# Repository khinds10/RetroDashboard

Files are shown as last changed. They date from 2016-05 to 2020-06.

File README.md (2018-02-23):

# DashboardPI - Retro Display Dashboard
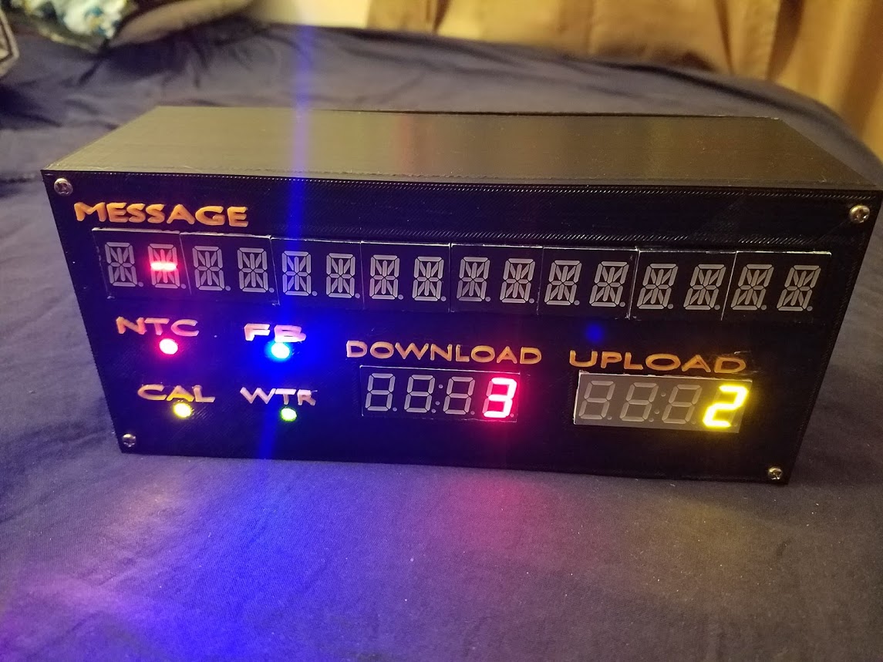
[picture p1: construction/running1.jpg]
Final Construction

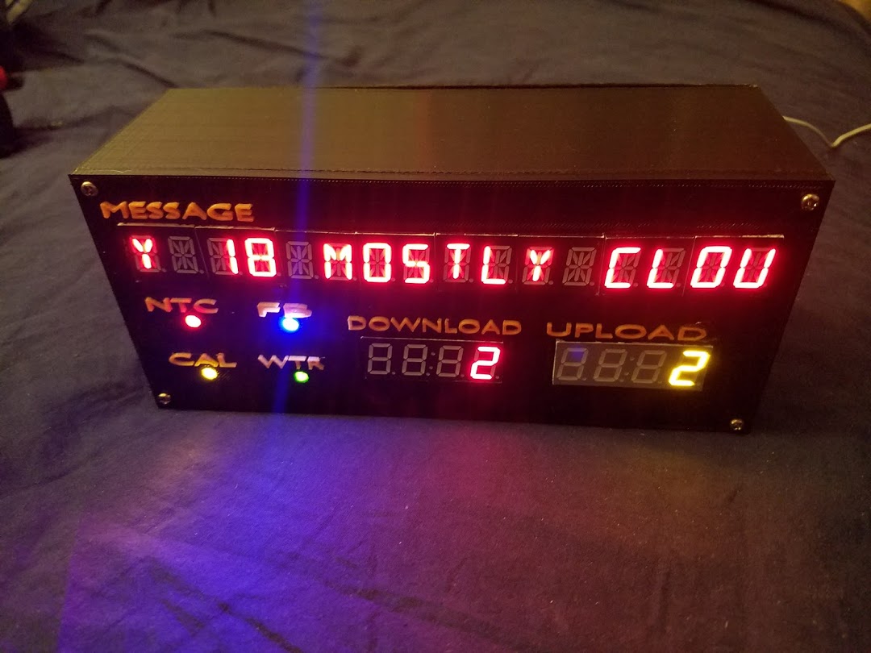
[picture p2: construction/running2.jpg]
Final Construction


#### Flashing RaspberriPi Hard Disk / Install Required Software (Using Ubuntu Linux)

Download "RASPBIAN JESSIE LITE"
https://www.raspberrypi.org/downloads/raspbian/

**Create your new hard disk for DashboardPI**
>Insert the microSD to your computer via USB adapter and create the disk image using the `dd` command
>
> Locate your inserted microSD card via the `df -h` command, unmount it and create the disk image with the disk copy `dd` command
> 
> $ `df -h`
> */dev/sdb1       7.4G   32K  7.4G   1% /media/XXX/1234-5678*
> 
> $ `umount /dev/sdb1`
> 
> **Caution: be sure the command is completely accurate, you can damage other disks with this command**
> 
> *if=location of RASPBIAN JESSIE LITE image file*
> *of=location of your microSD card*
> 
> $ `sudo dd bs=4M if=/path/to/raspbian-jessie-lite.img of=/dev/sdb`
> *(note: in this case, it's /dev/sdb, /dev/sdb1 was an existing factory partition on the microSD)*

**Setting up your RaspberriPi**

*Insert your new microSD card to the raspberrypi and power it on with a monitor connected to the HDMI port*

Login
> user: **pi**
> pass: **raspberry**

Change your account password for security
>`sudo passwd pi`

Enable RaspberriPi Advanced Options
>`sudo raspi-config`

Choose:
`1 Expand File System`

`9 Advanced Options`
>`A2 Hostname`
>*change it to "DashboardPI"*
>
>`A4 SSH`
>*Enable SSH Server*
>
>`A7 I2C`
>*Enable i2c interface*

**Enable the English/US Keyboard**

>`sudo nano /etc/default/keyboard`

> Change the following line:
>`XKBLAYOUT="us"`

**Reboot PI for Keyboard layout changes / file system resizing to take effect**
>$ `sudo shutdown -r now`

**Auto-Connect to your WiFi**

>`sudo nano /etc/wpa_supplicant/wpa_supplicant.conf`

Add the following lines to have your raspberrypi automatically connect to your home WiFi
*(if your wireless network is named "linksys" for example, in the following example)*

	network={
	   ssid="linksys"
	   psk="WIRELESS PASSWORD HERE"
	}

**Reboot PI to connect to WiFi network**

>$ `sudo shutdown -r now`
>
>Now that your PI is finally on the local network, you can login remotely to it via SSH.
>But first you need to get the IP address it currently has.
>
>$ `ifconfig`
>*Look for "inet addr: 192.168.XXX.XXX" in the following command's output for your PI's IP Address*

**Go to another machine and login to your raspberrypi via ssh**

> $ `ssh pi@192.168.XXX.XXX`

**Start Installing required packages**

>$ `sudo apt-get update`
>
>$ `sudo apt-get upgrade`
>
>$ `sudo apt-get install vim git python-smbus i2c-tools python-imaging python-smbus build-essential python-dev rpi.gpio python3 python3-pip`

**Update local timezone settings

>$ `sudo dpkg-reconfigure tzdata`

`select your timezone using the interface`

**Setup the simple directory `l` command [optional]**

>`vi ~/.bashrc`
>
>*add the following line:*
>
>`alias l='ls -lh'`
>
>`source ~/.bashrc`

**Fix VIM default syntax highlighting [optional]**

>`sudo vi  /etc/vim/vimrc`
>
>uncomment the following line:
>
>_syntax on_

**Install i2c Backpack Python Drivers**

>$ `git clone https://github.com/adafruit/Adafruit_Python_LED_Backpack`

>$ `cd Adafruit_Python_LED_Backpack/`

>$ `sudo python setup.py install`

# Supplies Needed

Raspberry PI or Pi Zero

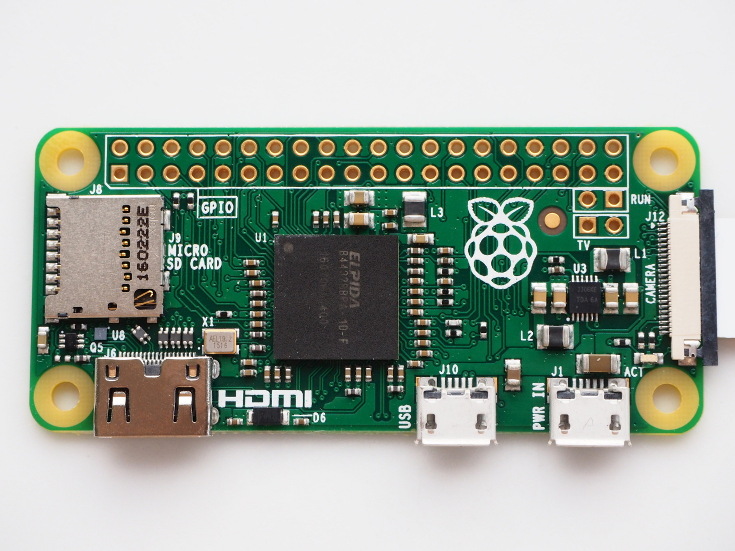
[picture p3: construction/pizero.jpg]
PiZero


0.56" 4-Digit 7-Segment Display w/I2C Backpack (x2)

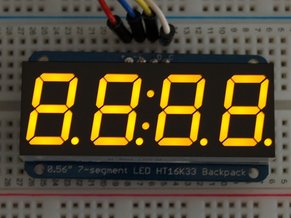
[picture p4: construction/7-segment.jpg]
7 Segment Display


Quad Alphanumeric Display - 0.54" Digits w/ I2C Backpack (x4)

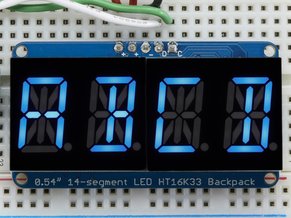
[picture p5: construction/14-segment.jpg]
14 Segment Display


LED Lights (x4)

LED Lights

# Building the Dashboard

## 1) Using a 3d printer, print the cover, box and back panels

Using the following 3 STL files in the `/construction/3D Print/` folder, print out the cover, box and back of the case to assemble.
>Dashboard-cover.stl
>Dashboard-box.stl
>Dashboard-back.stl

## 2) Solder Unique Display Jumpers
*NOTE: All the I2C backpacks must be soldered on the back of each of the displays, the backpacks come with the display and must all be soldered on first.*

For each of the I2C backpack displays you must solder the jumpers on the back in the **all the possible combinations** to have your RaspberriPI I2C interface to recognize each display with a **unique address**.  

Leave the first display with no jumper soldered, the 2nd with the farthest right soldered, the 3rd with only the middle soldered and so on...  Eventually you'll have to solder jumpers in all the combinations of 2 at a time connected and the final display with all 3 jumpers soldered to be connected.

*There's a total of 3 pins so you should have a total combination of 8 unique combinations.*

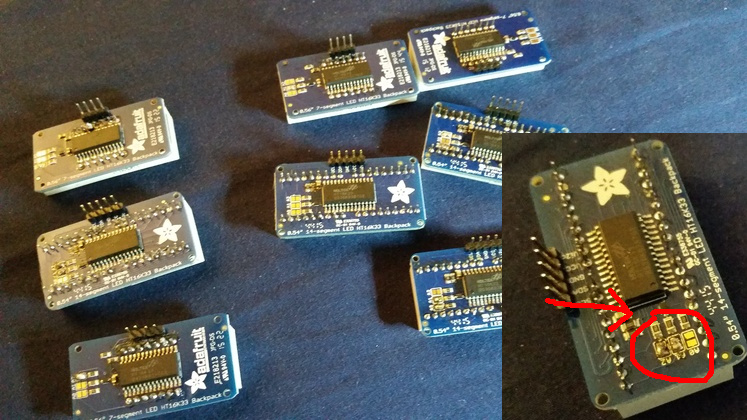
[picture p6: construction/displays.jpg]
Solder Unique Display Jumpers


## 3) Mount Displays in box
Using a hot glue gun, mount the displays in the holes and glue them in place.  The LED lights may hold by friction from the 3D printed design, else use hot glue to hold them in place as well.

**NOTE: I have written down on the back of the box cover the HEX addresses x70 - x77 that each display has based on the soldering jumpers (see section #2)**

## 4) Wiring all Displays

Each of the 14 segment alpha numeric displays needs to have a connection to the RaspberryPI GND, 5V and 3V pins.  The 7 segment display only needs connectivity to the GND and 5V pins.

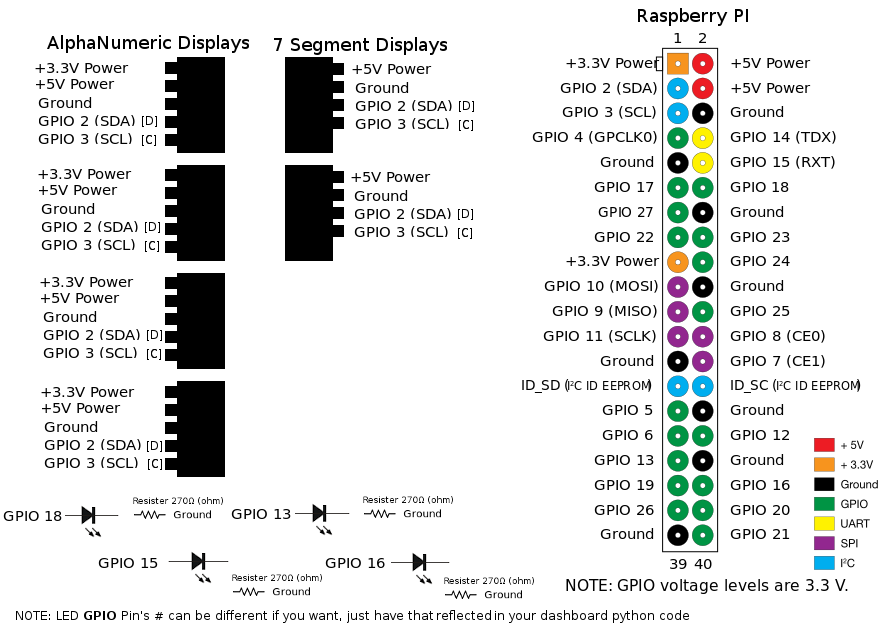
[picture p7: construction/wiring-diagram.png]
Wiring Diagram


I've used standard jumper wires to connect to all the pins on the display / RaspberryPI pins and grouped the common connections (all the GND wires, 5V wires) with a wirenut.

Each LED light needs to have a 270 ohm resister solder to the ground (short) pin and connect each positive LED pin to the corresponding GPIO pins on the PI, I've used GPIO pins 18, 13, 15 and 16.

For each display in the dashboard ALL of the D and C pins need to be connected to the SCL and SDA pins on the PI.

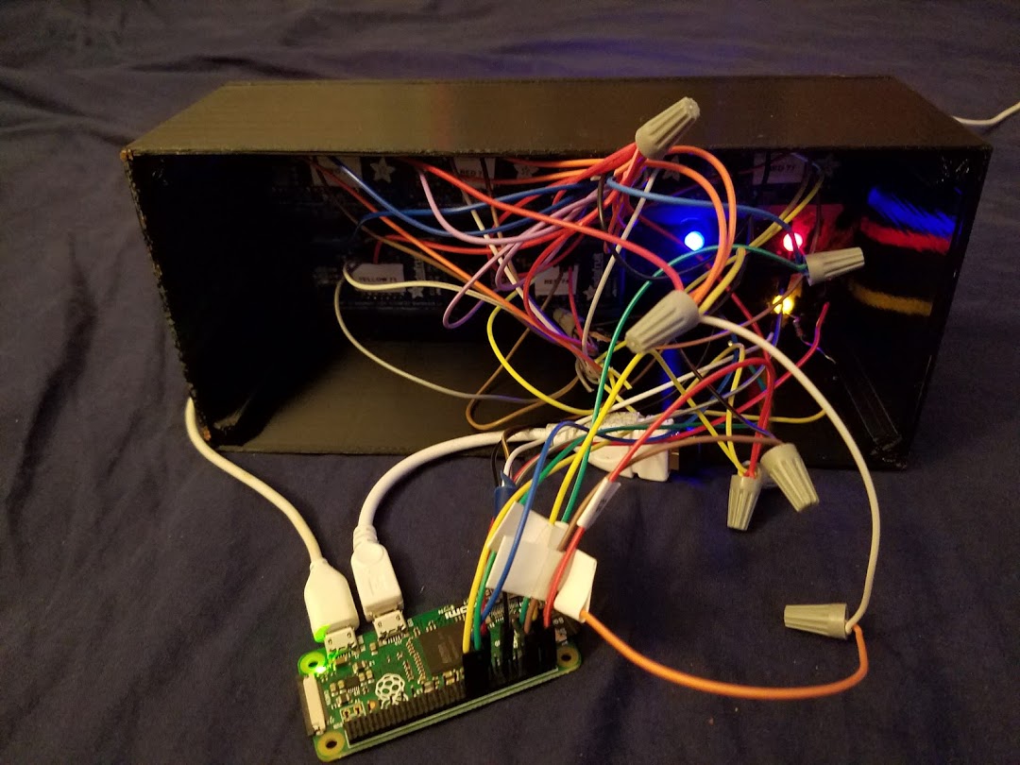
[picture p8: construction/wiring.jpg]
Mount Displays

## 5) Finished (Final Touches)

**Screw the front cover and back panel to the main box**

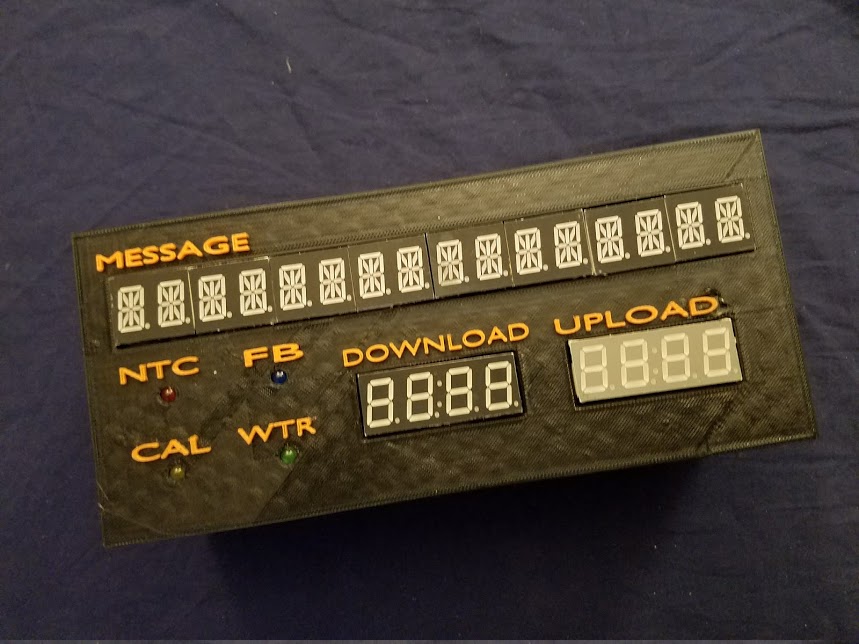
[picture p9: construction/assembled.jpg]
Front

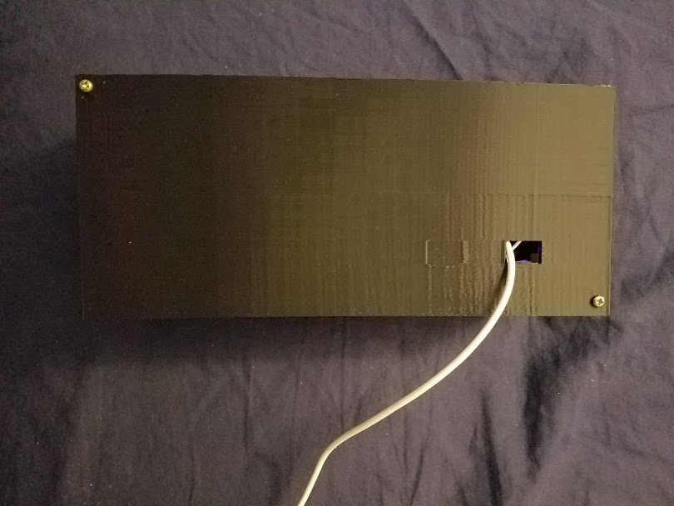
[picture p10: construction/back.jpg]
Back back


You're now ready to run the Dashboard!

## 7) Install Central Webhost 
This project includes a small PHP server that you can host on almost any low cost linux webhost.  From this project copy the files from the "server/" folder and place them on your PHP webhost and remember the domain name.  
> For our example it will be installed on a hypothetical host with the public domain name of: www.mydashboard.com

The **server/README.md** file contains all the details about how to get/set message values, measurement values and flag values to the PHP server.  These values will then be listened for on the Retrodashboard to display to you as output via the alphanumeric / numeric and led lights turning on and off.

## 8) Install & Run Dashboard Drivers

Start up your RaspberryPi and make sure the I2C bus recognizes all your connected 7/14 segment displays. 
*[each display is given a unique address described above by how you solder each display's jumpers in different combinations]*

If you have all 8 displays with jumpers soldered in all 8 combinations, you should have the following output for the `i2cdetect` command:

`sudo i2cdetect -y 1`
     
>    0  1  2  3  4  5  6  7  8  9  a  b  c  d  e  f
>
> 00:          -- -- -- -- -- -- -- -- -- -- -- -- -- 
> 
> 10: -- -- -- -- -- -- -- -- -- -- -- -- -- -- -- -- 
> 
> 20: -- -- -- -- -- -- -- -- -- -- -- -- -- -- -- -- 
> 
> 30: -- -- -- -- -- -- -- -- -- -- -- -- -- -- -- -- 
> 
> 40: -- -- -- -- -- -- -- -- -- -- -- -- -- -- -- -- 
> 
> 50: -- -- -- -- -- -- -- -- -- -- -- -- -- -- -- -- 
> 
> 60: -- -- -- -- -- -- -- -- -- -- -- -- -- -- -- -- 
> 
> 70: 70 71 72 73 74 75 76 77

*(in this case all the displays numbered 0 to 7 are being recognized on the PI as I2C available devices)*

**Install all 3 python driver scripts from this project (in the dashboard/ folder) to your home directory of the RaspberryPI. **
So your PI has the following home directory files:

`cd ~`
`ls -lh`

    -rwxrwxr-x 1 pi pi 2.8K May 21 01:56 alphanum.py
    -rwxrwxr-x 1 pi pi 2.2K May 21 01:54 dashboard.py
    -rwxrwxr-x 1 pi pi 1.4K May 21 02:36 indicators.py

Edit each python scripts variable to reference your running PHP data server (see Step 7)

	dashboardServer = 'CHANGE TO YOUR SERVER.com'

**alphanum.py**

*Change the python code to reflect the HEX addresses each display is assigned based on the solder jumpers (see section #2)*

	display1 = AlphaNum4.AlphaNum4(address=0x77, busnum=1)
	display2 = AlphaNum4.AlphaNum4(address=0x76, busnum=1)
	display3 = AlphaNum4.AlphaNum4(address=0x75, busnum=1)
	display4 = AlphaNum4.AlphaNum4(address=0x73, busnum=1)
	
**dashboard.py**

*Change the python code to reflect the HEX addresses each display is assigned based on the solder jumpers (see section #2)*

	blueDisplay = SevenSegment.SevenSegment(address=0x70, busnum=1) 
	yellowDisplay = SevenSegment.SevenSegment(address=0x71, busnum=1) 
	greenDisplay = SevenSegment.SevenSegment(address=0x72, busnum=1) 
	redDisplay = SevenSegment.SevenSegment(address=0x74, busnum=1)
	
**indicators.py**

*Change the python code to reflect the GPIO pin numbers each LED is assigned based on your exact wiring (I've used GPIO pins: 13,15,16,18)

	GPIO.setup(18, GPIO.OUT)
	GPIO.output(18,GPIO.LOW)
	GPIO.setup(13, GPIO.OUT)
	GPIO.output(13,GPIO.LOW)
	GPIO.setup(15, GPIO.OUT)
	GPIO.output(15,GPIO.LOW)
	GPIO.setup(16, GPIO.OUT)
	GPIO.output(16,GPIO.LOW)

Now that your 3 scripts are pointing to your own data server you're now ready to run the dashboard to display your output.

Run the following commands to start your Dashboard displays.

$  `nohup python indicators.py > indicators.out &`

$  `nohup python dashboard.py > dashboard.out &`

$  `nohup python alphanum.py > alphanum.out &`

This will allow you to logout of your PI and have the python drivers remain running as a background process, if they do fail for any reason, the error message will be found in the [.out] from the commands above.

**Run Displays at system startup**

Place the following entries in the Dashboard crontab to have it run the scripts on system start/reboot.  Note: logging to [.out] files has been supressed in this case to /dev/null if you have any errors occuring.

$ `crontab -e`

`@reboot nohup python /home/pi/indicators.py >/dev/null 2>&1`
`@reboot nohup python /home/pi/dashboard.py >/dev/null 2>&1`
`@reboot nohup python /home/pi/alphanum.py >/dev/null 2>&1`

## 9) Running Plugins for Populating Display Data

#### (These plugins run on different machines of your choosing for the dashboard to then monitor them)

The **'plugins/'** folder contains plugins to get started populating the central server with information that the dashboard will display as output.

**network-monitor.py**

*This plugin will persist to the central data hub local network information such as your current upload and download speed in KBPS.*

**Software Requirements:**

ifstat is required

	sudo apt-get install ifstat

Configure and run the script:

	dashboardServer = 'CHANGE TO YOUR SERVER.com'

$  `nohup python network-monitor.py > network-monitor.out &`

**server-monitor.py**

*This plugin will persist to the central data hub local CPU usage and temperature statistics.*

**Software Requirements:**

psensor-server is required

	sudo apt-get install psensor-server

Configure the script:

	dashboardServer = 'CHANGE TO YOUR SERVER.com'

Run pensor server on port 17510, then run the server monitor script:

$ `nohup psensor-server -p 17510 > /dev/null 2>&1`

$ `nohup python server-monitor.py > server-monitor.out &`

**DashboardPhone/**

*This is a fully functional Android App that runs on your phone as a service and will persist to the central data hub notifications and indicator flags (coming soon).*

**Configure the App**
You need to update the settings.java file with your local settings

		// host with the PHP server script installed for the RetroDashboard
		public static String remoteDashboardHost = "CHANGE TO YOUR SERVER.com";
	
		// create a list of notifications (by title) your phone always produces but don't need to broadcast
		public static String[] ignoredNotifications = new String[] { "Privacy Guard active", "Change keyboard" };

**Build the App**

Using an Android IDE, import the project locally and build it to an APK file.  Install the APK on your phone locally and it should start working for you.

**PushBullet/**

*Using the pushbullet app for your phone, signup to recieve an API key to have a simple python script be able to capture and push data hub notifications and indicator flags*

Install Python 3.5 for asyncio functionality

	sudo apt-get update
	sudo apt-get install build-essential tk-dev
	sudo apt-get install libncurses5-dev libncursesw5-dev libreadline6-dev
	sudo apt-get install libdb5.3-dev libgdbm-dev libsqlite3-dev libssl-dev
	sudo apt-get install libbz2-dev libexpat1-dev liblzma-dev zlib1g-dev

If one of the packages cannot be found, try a newer version number (e.g. libdb5.4-dev instead of libdb5.3-dev).

	wget https://www.python.org/ftp/python/3.5.2/Python-3.5.2.tgz
	tar zxvf Python-3.5.2.tgz
	cd Python-3.5.2
	./configure --prefix=/usr/local/opt/python-3.5.2
	make
	sudo make install
	sudo ln -s /usr/local/opt/python-3.5.2/bin/pydoc3.5 /usr/bin/pydoc3.5
	sudo ln -s /usr/local/opt/python-3.5.2/bin/python3.5 /usr/bin/python3.5
	sudo ln -s /usr/local/opt/python-3.5.2/bin/python3.5m /usr/bin/python3.5m
	sudo ln -s /usr/local/opt/python-3.5.2/bin/pyvenv-3.5 /usr/bin/pyvenv-3.5
	sudo ln -s /usr/local/opt/python-3.5.2/bin/pip3.5 /usr/bin/pip3.5
	cd ~
	echo 'alias python35="/usr/local/opt/python-3.5.2/bin/python3.5"' >> .bashrc
	echo 'alias idle35="/usr/local/opt/python-3.5.2/bin/python3.5"' >> .bashrc

Install the python3 dependancies

	sudo apt-get install python3-setuptools
	sudo apt-get install python3-pip
	pip3 install asyncpushbullet

*Optional way* Download the python repository directly to obtain the python dependancies without the use of pip installing it

    git clone https://github.com/rharder/asyncpushbullet
    cd asyncpushbullet && sudo /usr/local/opt/python-3.5.2/bin/python3.5 setup.py install

Copy the `PushBullet/` folder of the dashboard `plugins/` from this project to the dashboard pi.

Visit the pushbullet settings page in your account to generate an API key to use
https://www.pushbullet.com/#settings

Configure your `pushbullet-listener.py` script to have the correct API and dashboard central host

	# your API Key from PushBullet.com
	API_KEY = "o.XXXYYYZZZ111222333444555666"

	# dashboard central server host
	dashboardServer = 'MY-SERVER-HERE.com'

Add the script to start at dashboard boot and restart your dashboard pi

$ `crontab -e`

`@reboot nohup /usr/local/opt/python-3.5.2/bin/python3.5 /home/pi/PushBullet/pushbullet-listener.py >/dev/null 2>&1`

*Optional Date and Time Output* - instead of having internet upload/download speed use the following script to show the date and time instead

In the Crontab Change:

`@reboot nohup python /home/pi/dashboard.py >/dev/null 2>&1`

to: 

`@reboot nohup python /home/pi/date-time.py >/dev/null 2>&1`

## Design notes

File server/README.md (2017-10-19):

# RetroDashboard Central Data Hub

The following criteria will explain how to get information to output on your RetroDashboard as well as set it from various "plugins" you can write on your own.
*This is a small PHP script to place on a webhost of your choosing.  It has the following API to get and set information to it. Note: don't forget to include the .htaccess file for proper URL routing to take place.*

## API

	http://myhost/message
		(get the current message set)

	http://myhost/message/set
		(HTTP POST a raw string value to this URL to set a new message)
	
	http://myhost/flag/{id}
		(get the current boolean status of the flag by integer: {id})

	http://myhost/flag/all
		(get all the current boolean status of all the flags as an array)

	http://myhost/flag/{id}/set
		(set the current boolean status to 'true' for the flag by integer: {id})

	http://myhost/flag/{id}/unset
		(set the current boolean status to 'false' for the flag by integer: {id})
	
	http://myhost/reading/{id}
		(get the current averaged value for the reading by integer: {id})

	http://myhost/reading/all
		(get the current averaged value for all the readings as an array)

	http://myhost/reading/{id}/set
		(HTTP POST a raw numeric value to this URL to add a new value to the current calculated average)  
			-- see below for how many values in total are compiled to the average value

## Configuation

The 'readings' values are calculated as averages of a certain number of recent persisted reading numeric values. Set the following constant to how many of the most recent readings should be included to produce the average.

***$readingsAverageLimit = 5;***

## Datastore	
Server will persist values to simple files located by naming conventions below. Note: {id} will be replaced by the real integer presented by the incoming request's URL.

	$valueFileFolder = 'values' (name of the folder to contain the measurement files)
	$messageFileName = 'message.msg' (name of the message text file)
	$readingsFilesNames = 'reading{id}.avg' (name of the CSV averaged readings file)
	$flagFilesNames = 'flag{id}.flg' (name of the boolean flag value flag file)

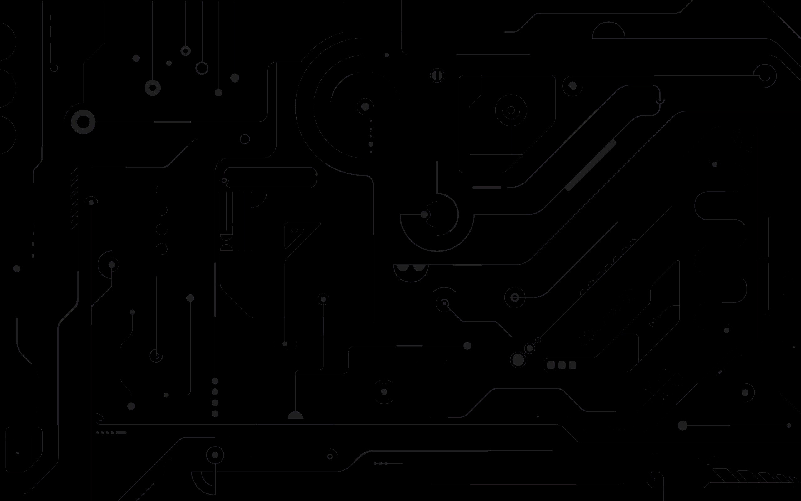
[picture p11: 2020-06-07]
server/img/background.jpg

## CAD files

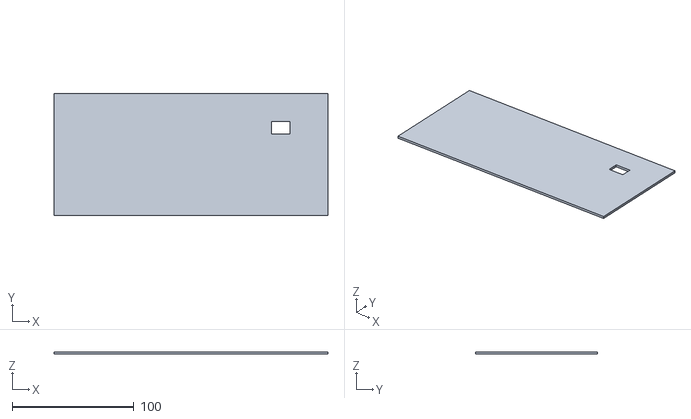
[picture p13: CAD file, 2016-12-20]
construction/3D Print/Dashboard-back.stl
225.0 x 100.0 x 2.00

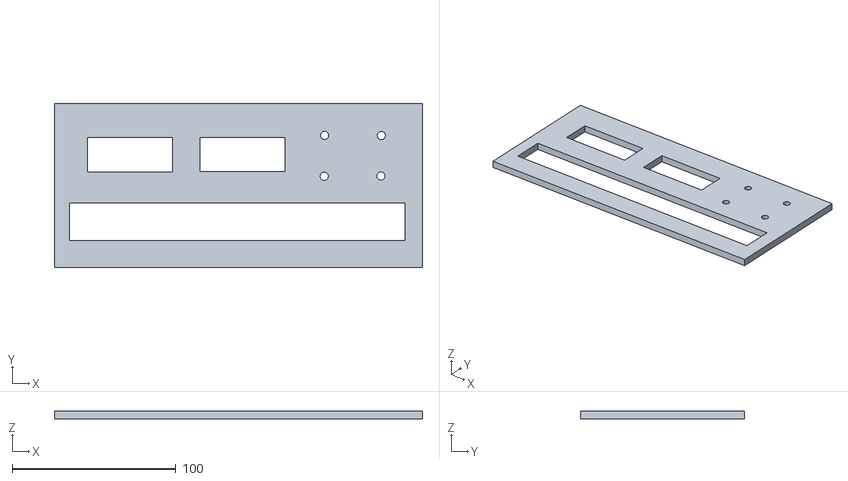
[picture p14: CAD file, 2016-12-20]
construction/3D Print/Dashboard-cover.stl
225.0 x 100.0 x 5.00

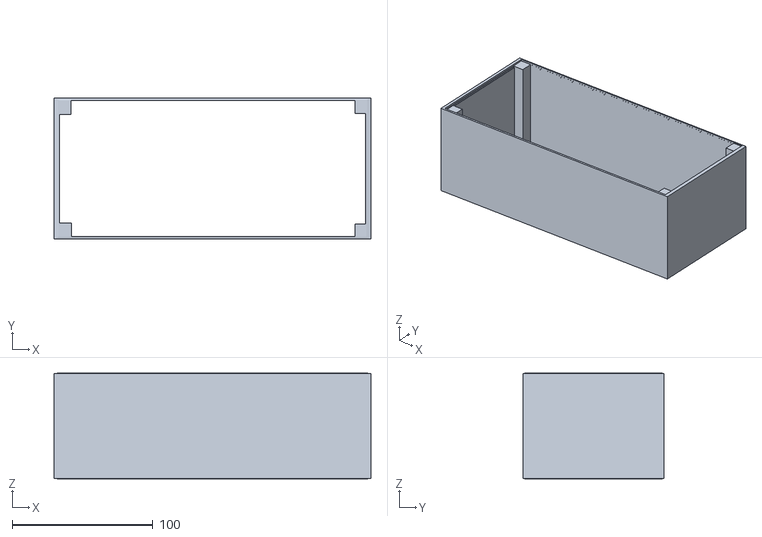
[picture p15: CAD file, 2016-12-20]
construction/3D Print/Dashboard-box.stl
225.0 x 100.0 x 75.0

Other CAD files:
construction/3D Print/Dashboard-back.blend
construction/3D Print/Dashboard-box.blend
construction/3D Print/Dashboard-cover.blend

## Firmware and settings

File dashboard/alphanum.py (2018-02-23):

#!/usr/bin/python
# RetroDashboard AlphaNumeric Messages Driver
# @author khinds
# @license http://opensource.org/licenses/gpl-license.php GNU Public License

import time, json
import string, cgi, subprocess, json, datetime
from Adafruit_LED_Backpack import AlphaNum4

# Setup pins and initialize all the displays
display1 = AlphaNum4.AlphaNum4(address=0x77, busnum=1)
display2 = AlphaNum4.AlphaNum4(address=0x75, busnum=1)
display3 = AlphaNum4.AlphaNum4(address=0x73, busnum=1)
display4 = AlphaNum4.AlphaNum4(address=0x76, busnum=1)

# dashboard central server host
dashboardServer = 'MY-SERVER-HERE.com'

# how many times to scroll the message
showMessageCount = 3

# how many total alpha numeric characters you have in the scroll
numberLEDCharacters = 16

def initialize(display):
    """ start up the display with a the minimal brightness """
    display.begin()
    display.set_brightness(3)

def writeMessage(display, message):
    display.clear()
    display.print_str(message)
    display.write_display()

# prep displays and set brightness
initialize(display1)
initialize(display2)
initialize(display3)
initialize(display4)

def showNewMessage(message):
    '''Scroll a message across the display'''
    messageBuffer = numberLEDCharacters * " "
    message = messageBuffer + message.upper() + messageBuffer
    messageLength = len(message)
    showMessageIteration = 0
    pos = 0
    while (showMessageIteration < (showMessageCount * messageLength)):
        writeMessage(display1, message[pos:pos+4])
        writeMessage(display2, message[pos+4:pos+8])
        writeMessage(display3, message[pos+8:pos+12])
        writeMessage(display4, message[pos+12:pos+16])
        pos += 1
        showMessageIteration += 1
        if pos > len(message) - numberLEDCharacters:
            pos = 0
        time.sleep(0.1)

def showStaticMessage(message):
    '''show static waiting message'''
    writeMessage(display1, message[0:4])
    writeMessage(display2, message[4:8])
    writeMessage(display3, message[8:12])
    writeMessage(display4, message[12:16])

# Begin new phone notifications listener
currentMessage = ''
staticMessageCounter = 0
while True:
    try:
        phoneDashboardInfo = json.loads(unicode(subprocess.check_output(['curl', "http://" + dashboardServer + "/message"]), errors='ignore'))
        message = str(phoneDashboardInfo["message"])
        if (message != currentMessage):
            currentMessage = message
            showNewMessage(currentMessage)
        else:
            d = datetime.datetime.now()
            showStaticMessage(d.strftime("%a%b%d %I%M %p"))
    except:
        pass
        
    time.sleep(2)

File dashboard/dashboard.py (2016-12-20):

#!/usr/bin/python
# RetroDashboard Numeric Messages Driver
# @author khinds
# @license http://opensource.org/licenses/gpl-license.php GNU Public License

import time, json
import string, cgi, subprocess, json
from Adafruit_LED_Backpack import SevenSegment

# setup the displays by colors
yellowDisplay = SevenSegment.SevenSegment(address=0x71, busnum=1) 
redDisplay = SevenSegment.SevenSegment(address=0x74, busnum=1)
blinkDecimal = True

# dashboard central server host
dashboardServer = 'MY-SERVER-HERE.com'

def initialize(display):
    """ start up the display with a the minimal brightness """
    display.begin()
    display.set_brightness(3)

def setReadingValue(display, reading, blinkDecimal):
    """ set the reading to the display in question and blink the decimal """
    display.clear()
    display.print_float(reading, 0)
    display.set_decimal(3, blinkDecimal)
    display.write_display()

def setToError(display):
    """ set the display to error state """
    display.clear()
    display.print_number_str("----", 0)
    display.write_display()

# initialize the displays
initialize(redDisplay)
initialize(yellowDisplay)

# start the dashboard
while(True):
    try:

        # get all 4 readings
        readingsInfo = json.loads(subprocess.check_output(['curl', "http://" + dashboardServer + "/reading/all"]))
        setReadingValue(redDisplay, int(readingsInfo['message'][0]), blinkDecimal)
        setReadingValue(yellowDisplay, int(readingsInfo['message'][1]), blinkDecimal)

        # invert the decimal blinking value and wait 2 seconds
        blinkDecimal = not blinkDecimal
        time.sleep(1)

    except:
        # show the error state on the dashboard displays  
        setToError(yellowDisplay)
        setToError(redDisplay)
        time.sleep(2)

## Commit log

2016-05-18 add python drivers for dashboard displays, update server to have get-all option for readings and indicator flags
2016-05-24 fixed bugs with the dashboard python, added construction images and the beginning of the readme instructions;
    [alphanum.py, dashboard.py, indicators.py]
2016-05-27 added wiring diagram
2016-06-01 updated typo on wiring diagram image and added the final notes about the plugins folder script usage
2016-06-06 added try catch for any network issues/outages
    [alphanum.py, dashboard.py, indicators.py]
2016-12-20 new construction with 3D printed case
    [Dashboard-back.blend, Dashboard-back.stl, Dashboard-box.blend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]
2016-12-20 update readme with construction notes
    [Dashboard-cover.blend, Dashboard-cover.stl, Dashboard-final.blend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]
